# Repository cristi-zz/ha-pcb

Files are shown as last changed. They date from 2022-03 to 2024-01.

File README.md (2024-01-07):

## Home automation PCB

The story behind this, can be found [on my blog](https://visoft.ro/hello/expanding-the-stack-designing-a-pcb/2023/01/11/)

It will hold a series of breakout boards for I2C IO expanders, 1Wire drivers, ADCs. All are controlled with a Raspberry Pi 3B+.

The 220V actuators are controlled by a board with 16 mechanical relays. The board is in turn controlled by PCF8575 chip that takes I2C commands and controls 16 I/O pins. Board is active on low (optocouplers), PCF8575 can sink more current (than it could source). Perfect match.

The 16 relay board is separate, from this PCB, only a pin header connection is made.

The temperature sensors are DS18B20 that work on 1 wire protocol. These are already mounted with Ethernet cables terminated with RJ45. The sensors are read/driven by 4 ds2482s-100 chips (RJ45 terminals and ds2482s-100 are on this PCB).
The RJ jacks must be galvanic!

There are some other relays/contactors/voltages that needs monitoring, all done by 2 ADS1115 16-Bit ADC, present on board.

The chips are already sourced and live on their breakout boards. The PCB is mainly THT because of sourcing issues (eg can't find ds2482s-100 anywhere, will reuse existing breakouts). Only SMD are the 3.5 audio jacks (for ADC) again because no THT could be sourced atm.

The Raspberry Pi connector is only 20 pin wide because only the first few are used (5V, 3.3, SDA, SCL, GND)

There is a spurious bug, all relays are ON when the 16 relay board is powered but the Raspberry (that powers the rest of the circuits) is OFF. So, a solid state relay is used to cut power to the relay board when the RaPi is shutted down.

With the exception of ADCs, the schema and design choices follow the existing (4 years old) system.

This repo is mainly for reviewing purposes.

**The story behind this PCB is on [www.visoft.ro](https://www.visoft.ro/beginner/expanding-the-stack-designing-a-pcb/2372/)**

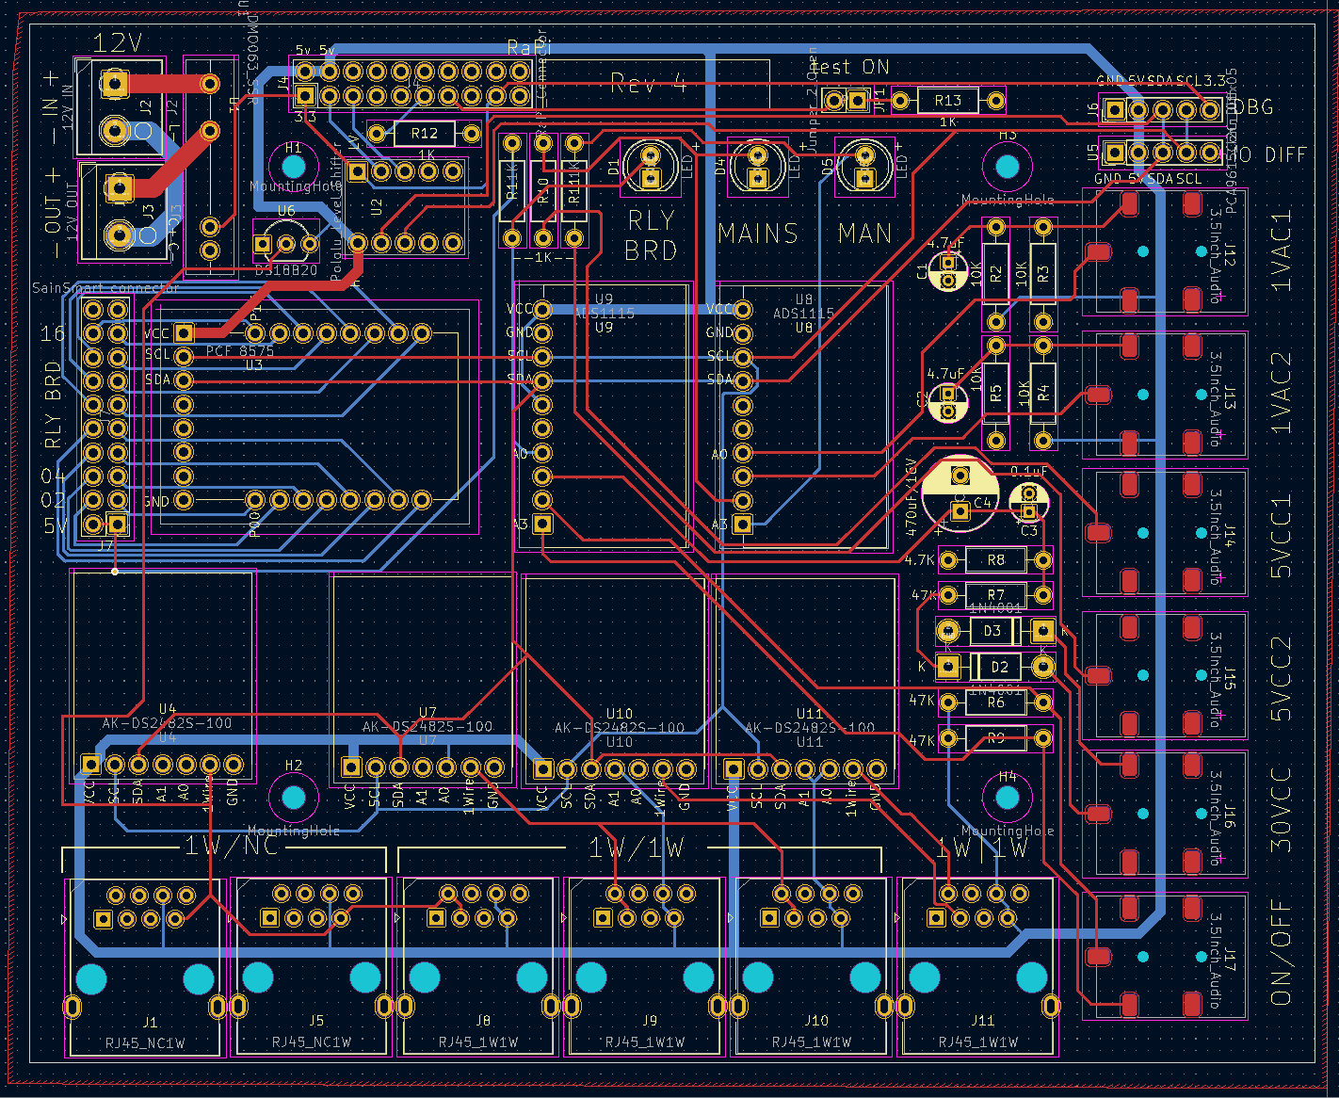
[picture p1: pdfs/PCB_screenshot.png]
PCB image with copper layers


A list with the devices

### Relay board that will be driven:
https://www.sainsmart.com/products/16-channel-12v-relay-module

### 16 channel IO expander that will drive the board:
https://www.artekit.eu/products/breakout-boards/io/ak-pcf8575-i2c-16-bit-io-expander-breakout/

### I2C level shifter (3.3 to 5V)
https://www.pololu.com/product/2595

### I2C to differential signals:
https://www.sparkfun.com/products/retired/14589

### 1Wire drivers:
https://www.artekit.eu/products/breakout-boards/io/ak-ds2482s-100/

### ADC:
https://www.adafruit.com/product/1085

Some ADC "watch" only for presence/absence of 5V power but some are listenting to CT sensors.
Quasi similar model: https://www.seeedstudio.com/Non-invasive-AC-Current-Sensor-30A-ma-p-519.html

### Solid state relay:
https://www.tme.eu/en/details/dmo063/dc-solid-state-relays/crydom/

Add comments here (as git issues) or on EEVBlog.

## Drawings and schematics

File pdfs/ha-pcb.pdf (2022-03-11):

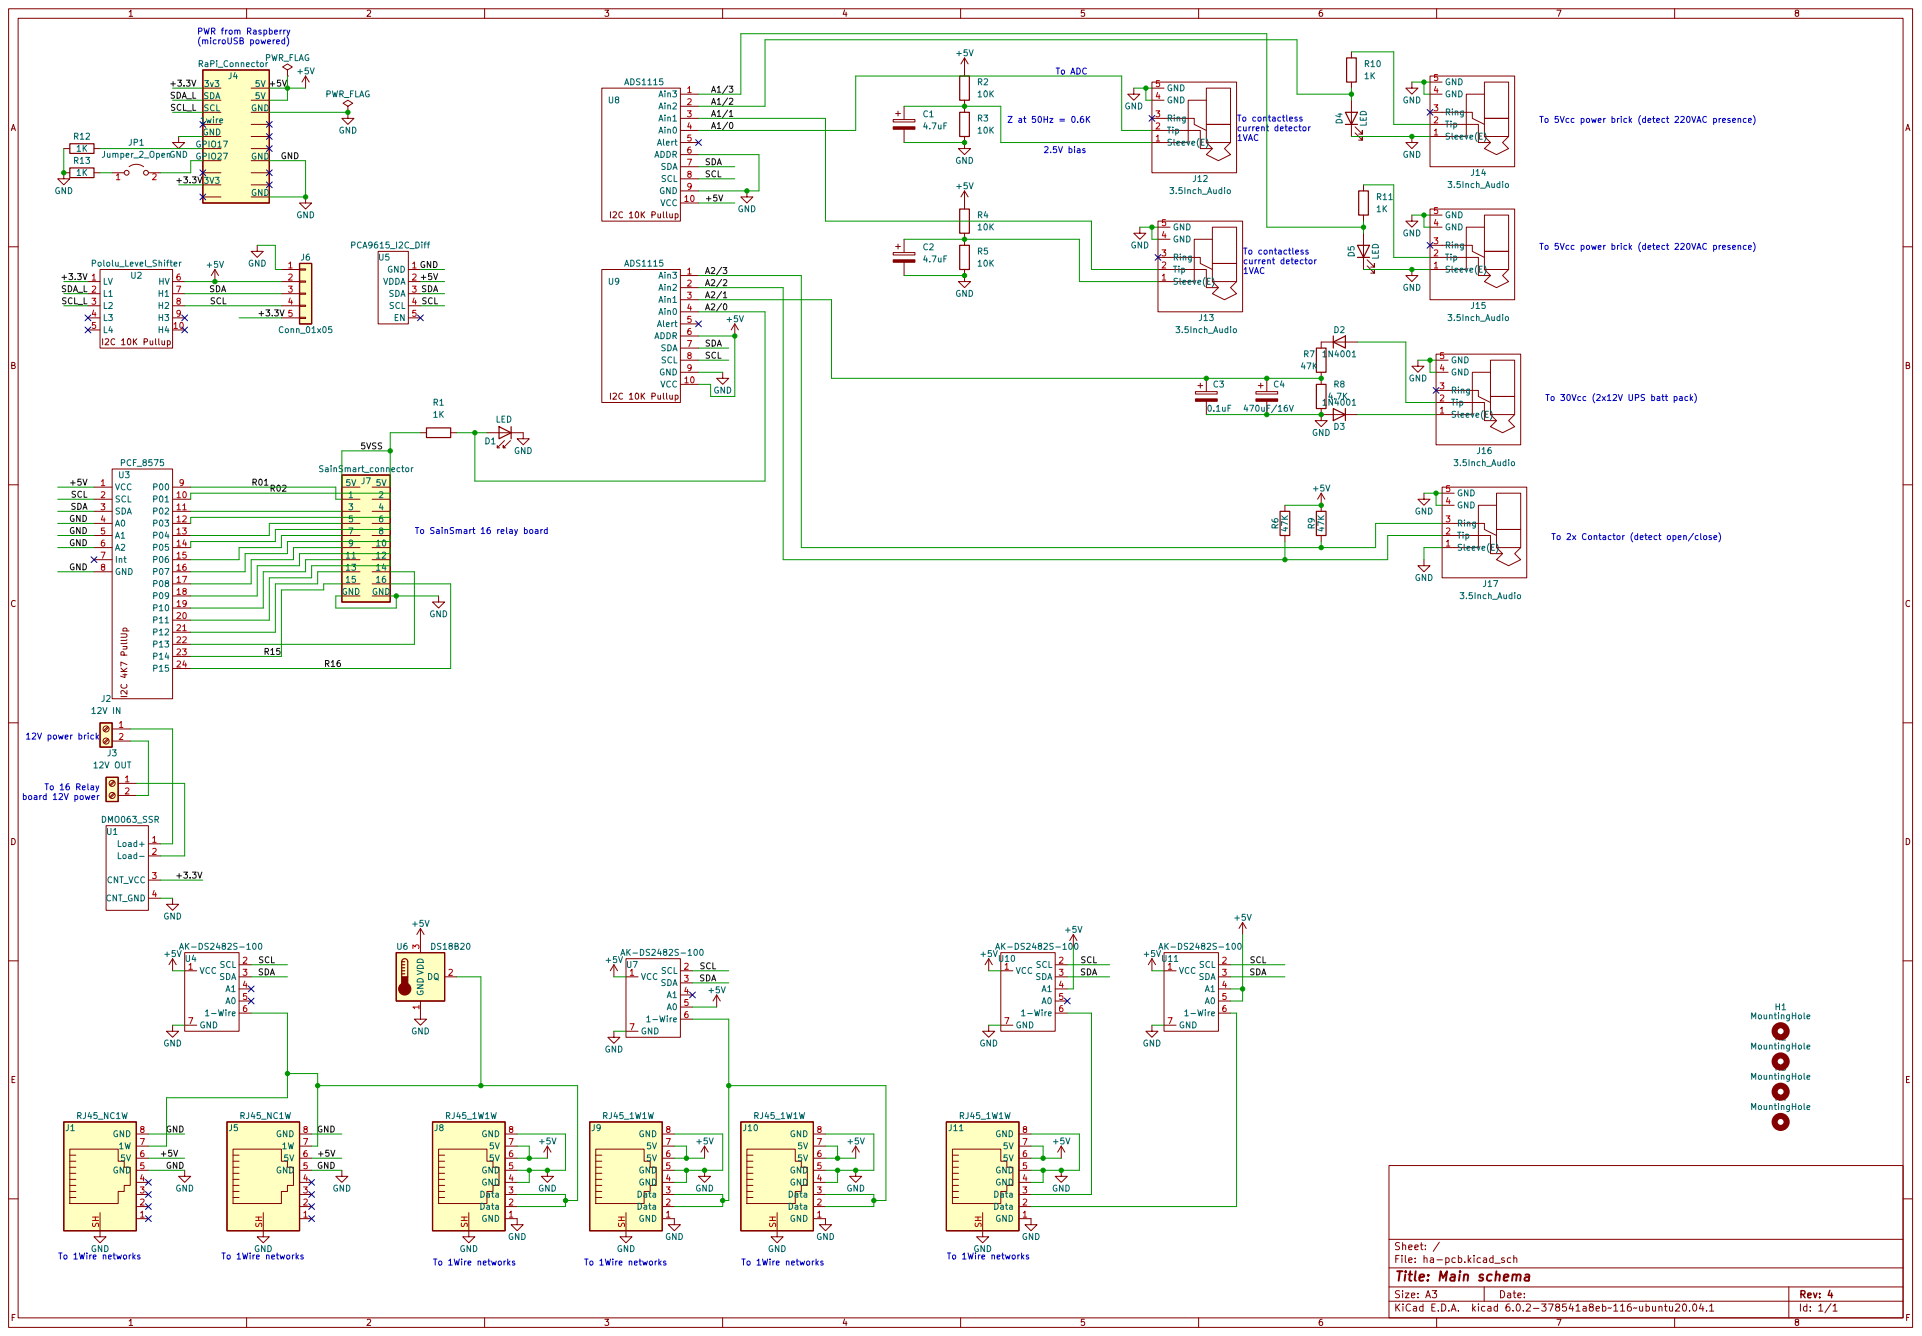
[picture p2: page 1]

To 5Vcc power brick (detect 220VAC presence)

To 30Vcc (2x12V UPS batt pack) To contactless
current detector 1VAC

5VSS R16 5V GND 5 6 7 8

Sleeve(E) 1 Tip 2 Ring 3 GND 4 GND 5

To SainSmart 16 relay board

File: ha-pcb.kicad_sch Sheet: / +5V

Id: 1/1 Title: Main schema

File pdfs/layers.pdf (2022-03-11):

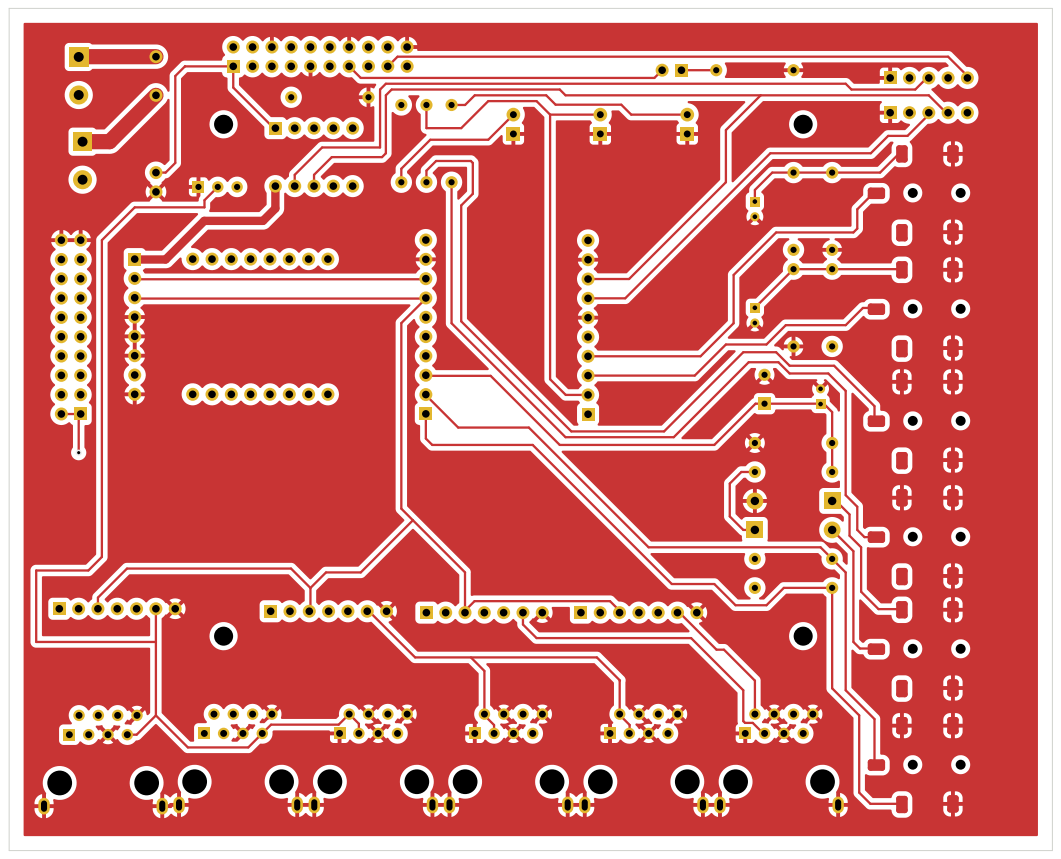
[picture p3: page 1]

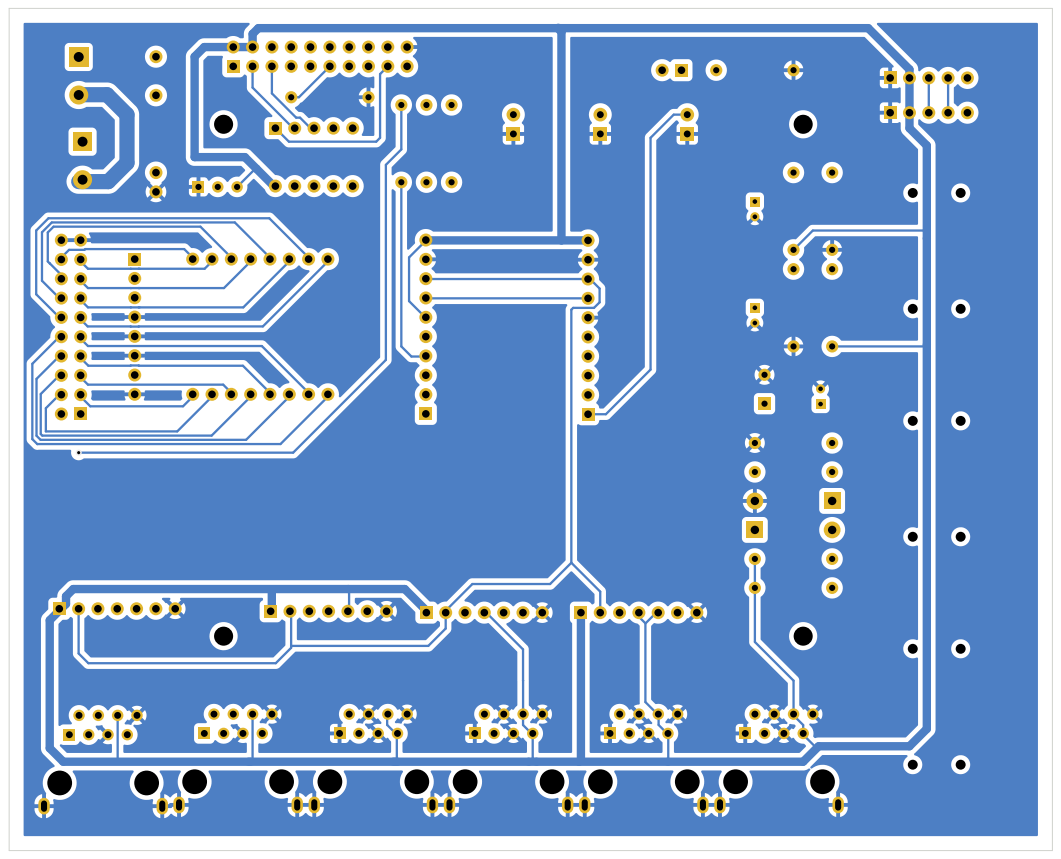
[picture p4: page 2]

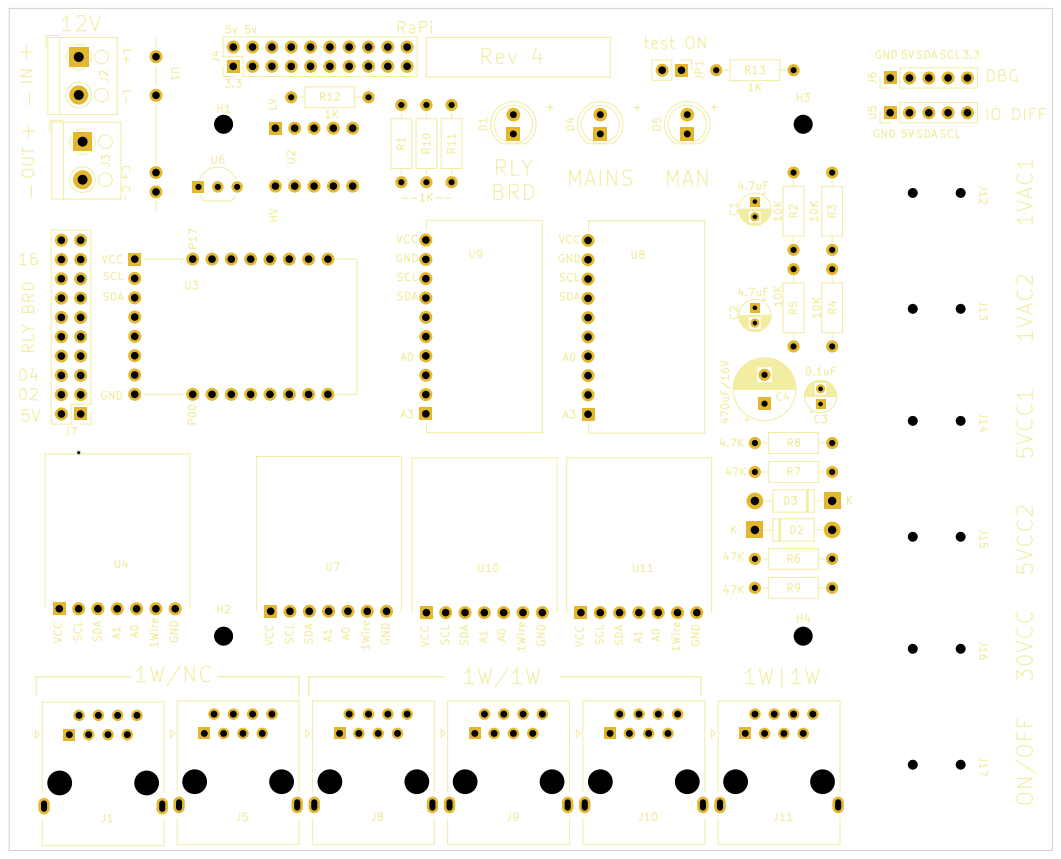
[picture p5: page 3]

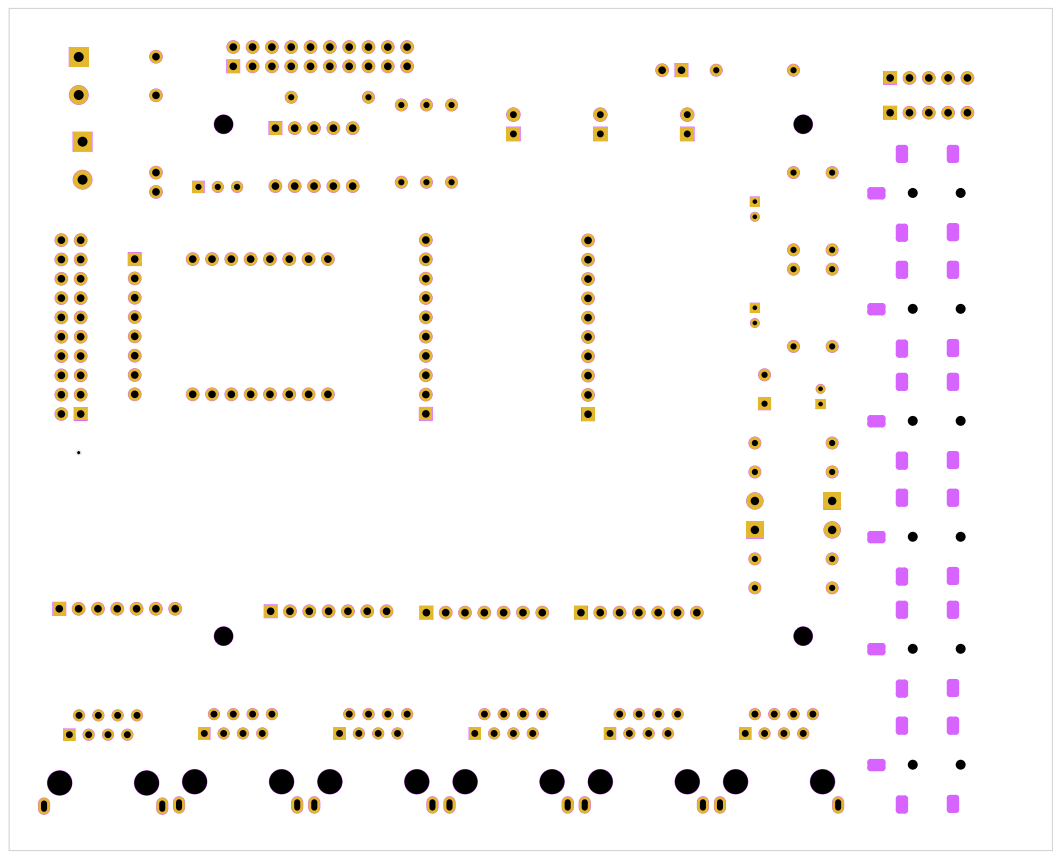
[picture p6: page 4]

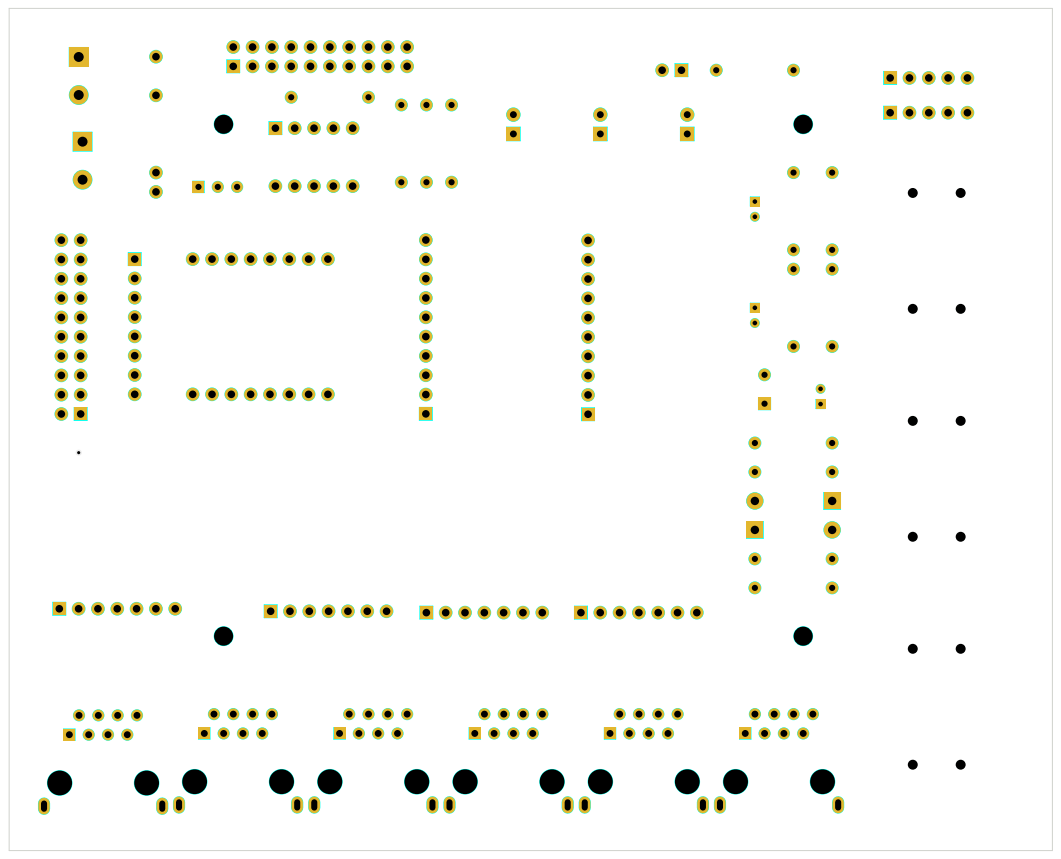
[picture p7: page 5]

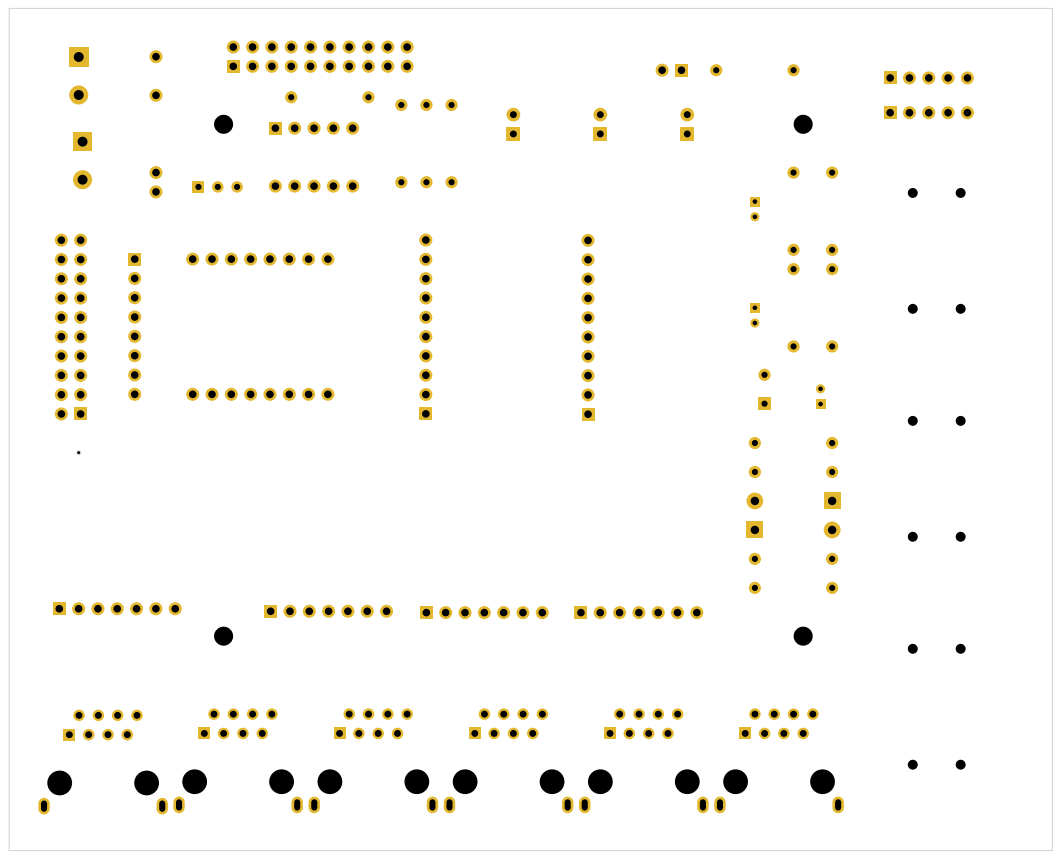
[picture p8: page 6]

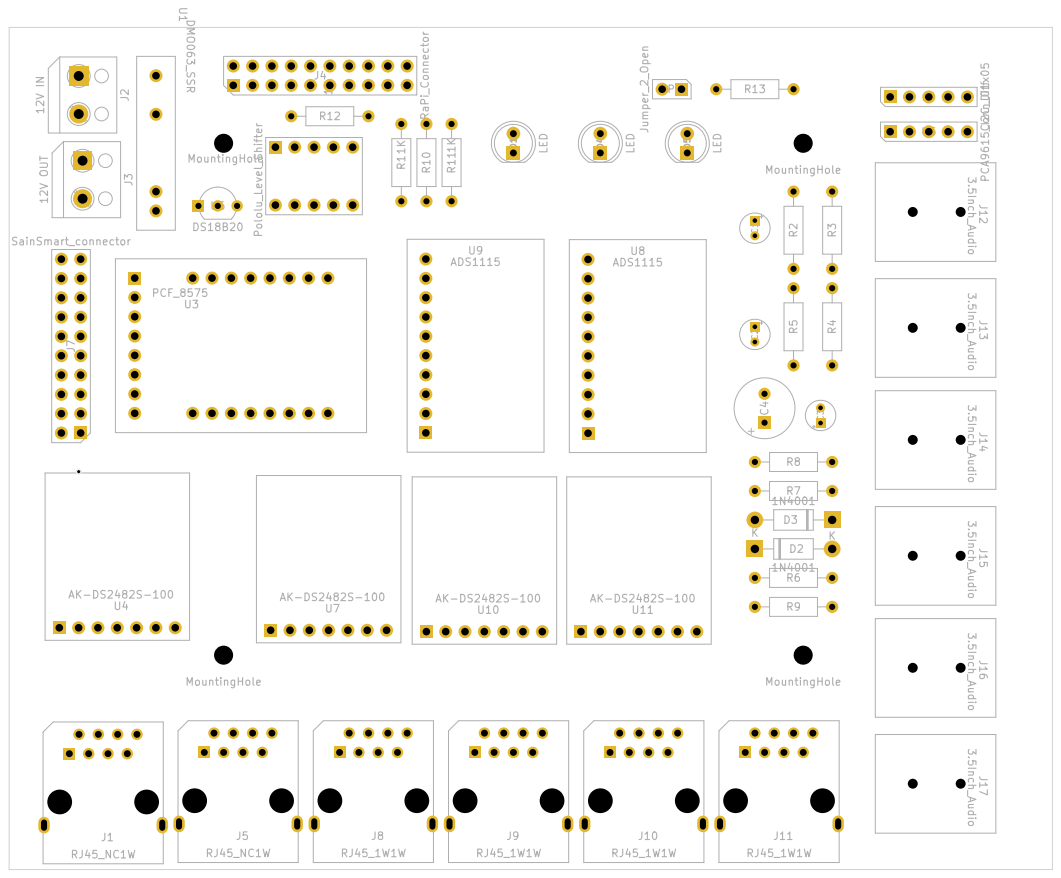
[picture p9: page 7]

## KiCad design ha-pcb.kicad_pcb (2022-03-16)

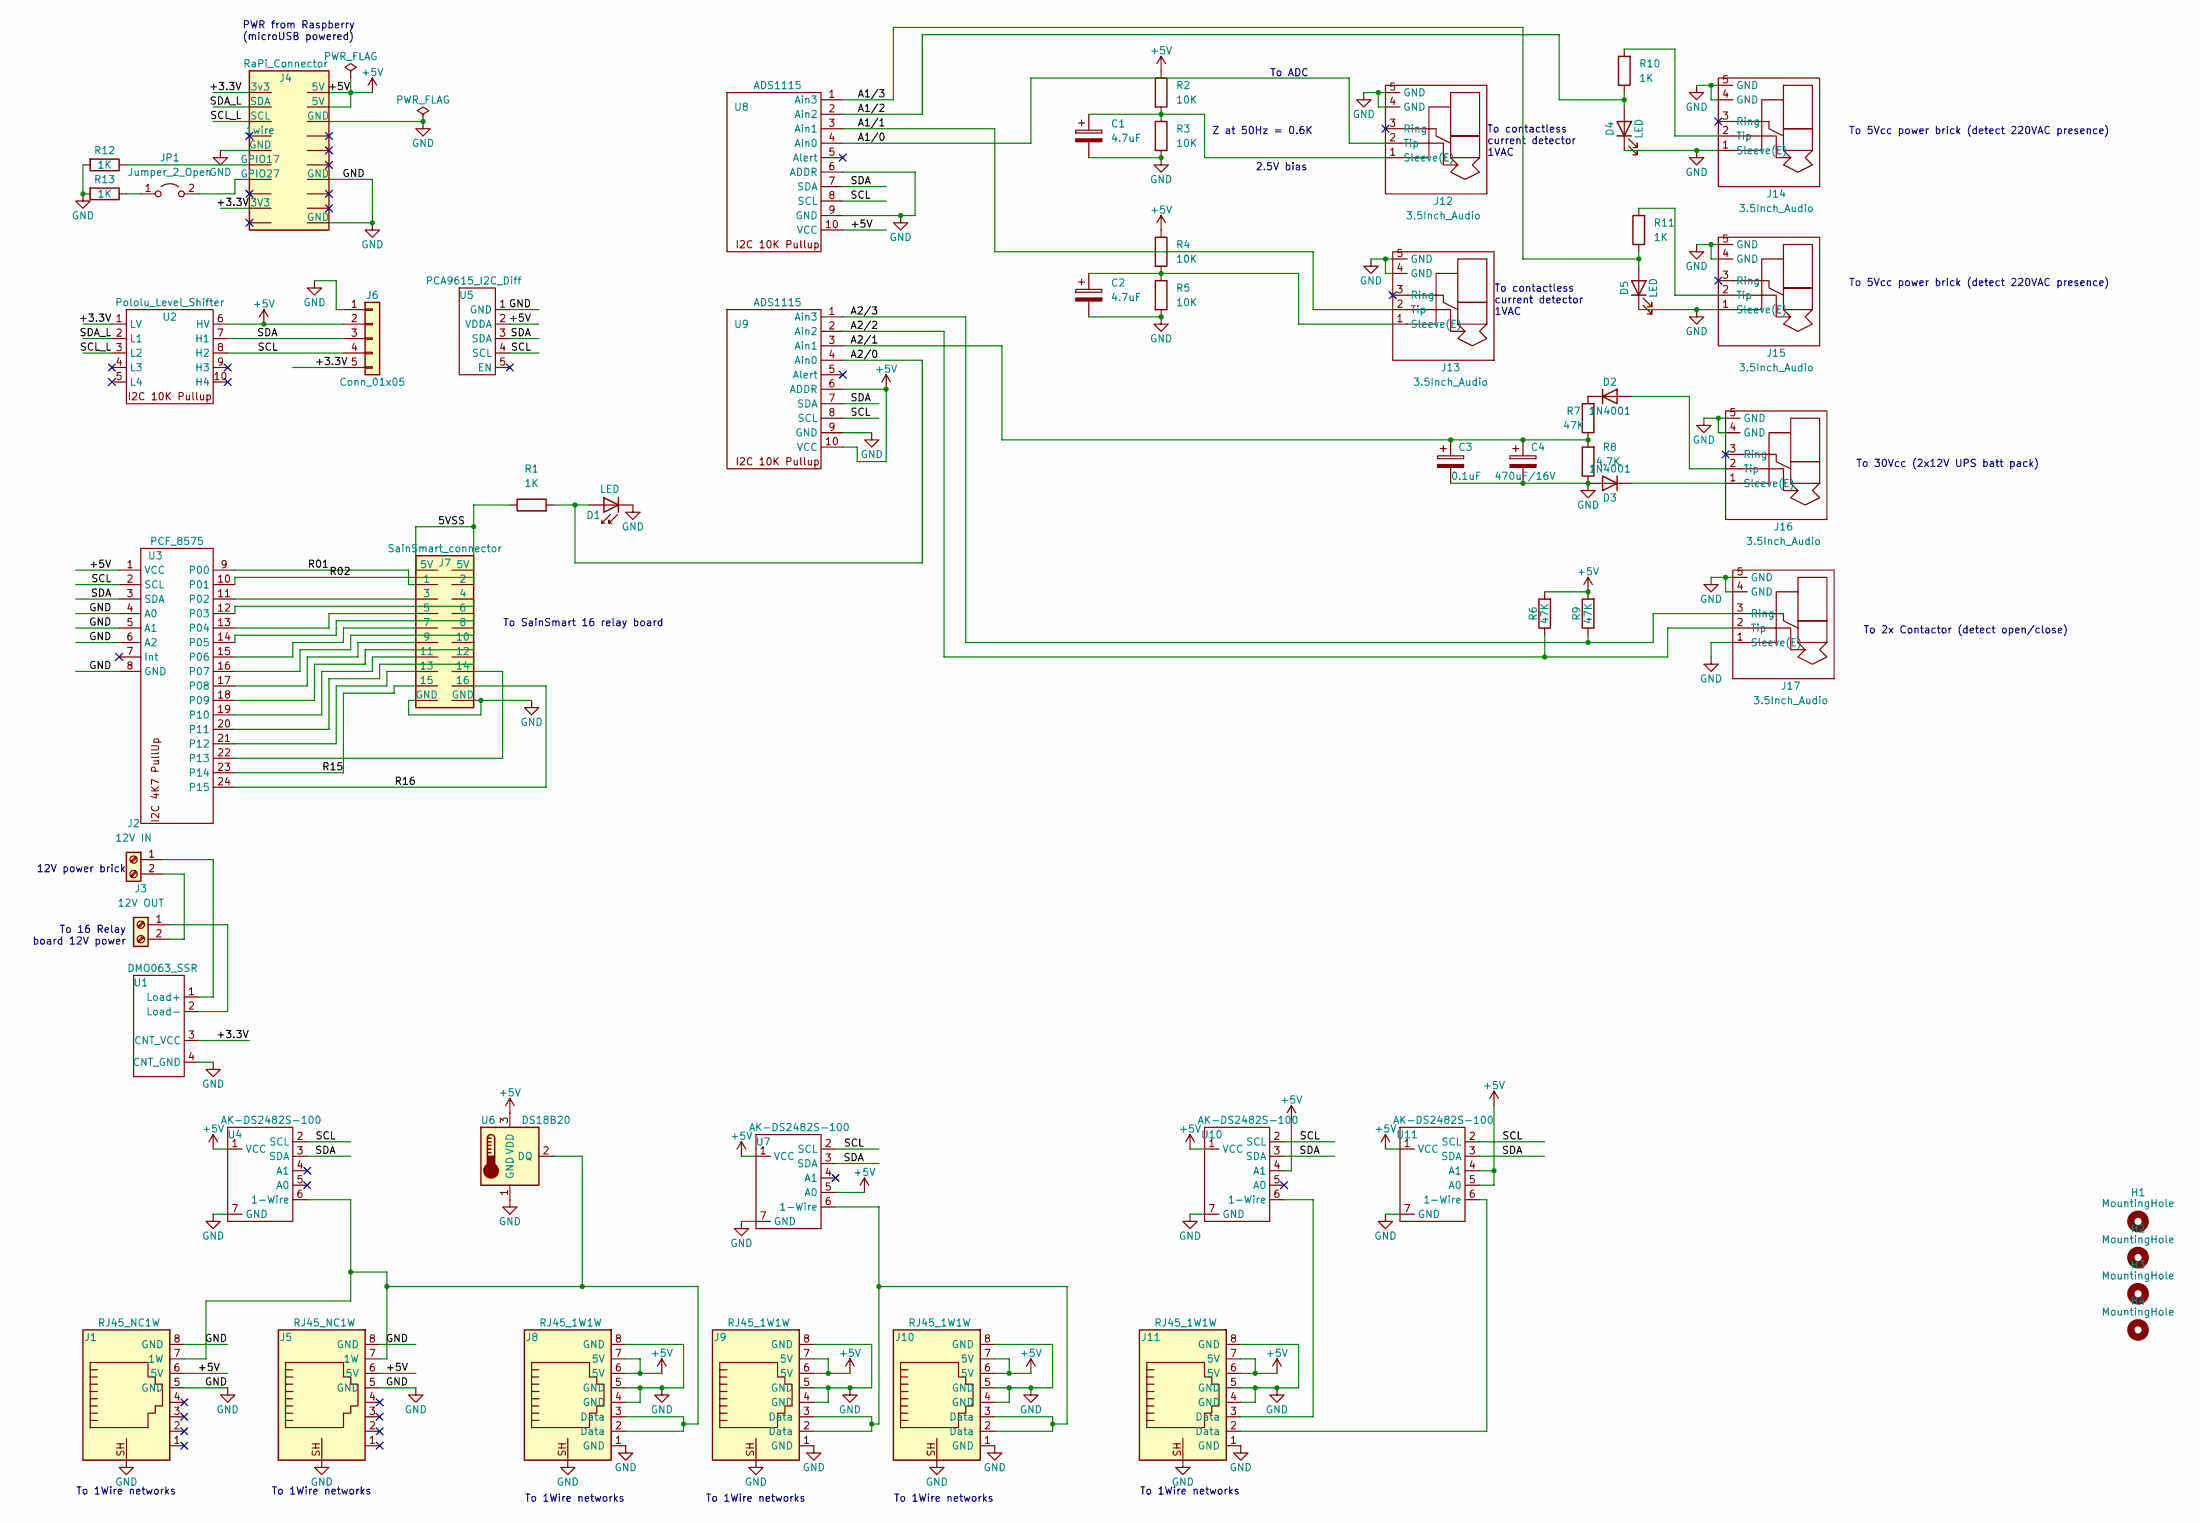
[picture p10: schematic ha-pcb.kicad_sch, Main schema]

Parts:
C1, C2: 4.7uF; CP_Radial_D4.0mm_P2.00mm
C3: 0.1uF; CP_Radial_D4.0mm_P2.00mm
C4: 470uF/16V; CP_Radial_D8.0mm_P3.80mm
D1, D4, D5: LED; LED_D5.0mm
D2, D3: 1N4001; D_DO-41_SOD81_P10.16mm_Horizontal
H1, H2, H3, H4: MountingHole; MountingHole_2.5mm
J1, J5: RJ45_NC1W; RJ45_Ninigi_GE_silver
J2: 12V IN; TerminalBlock_RND_205-00001_1x02_P5.00mm_Horizontal
J3: 12V OUT; TerminalBlock_RND_205-00001_1x02_P5.00mm_Horizontal
J4: RaPi_Connector; PinHeader_2x10_P2.54mm_Vertical
J6: Conn_01x05; PinHeader_1x05_P2.54mm_Vertical
J7: SainSmart_connector; PinHeader_2x10_P2.54mm_Vertical
J8, J9, J10, J11: RJ45_1W1W; RJ45_Ninigi_GE_silver
J12, J13, J14, J15, J16, J17: 3.5Inch_Audio; 3.5mmJack SMD
JP1: Jumper_2_Open; PinHeader_1x02_P2.54mm_Vertical
R1, R10, R11, R12, R13: 1K; R_Axial_DIN0207_L6.3mm_D2.5mm_P10.16mm_Horizontal
R2, R3, R4, R5: 10K; R_Axial_DIN0207_L6.3mm_D2.5mm_P10.16mm_Horizontal
R6, R7, R9: 47K; R_Axial_DIN0207_L6.3mm_D2.5mm_P10.16mm_Horizontal
R8: 4.7K; R_Axial_DIN0207_L6.3mm_D2.5mm_P10.16mm_Horizontal
U1: DMO063_SSR
U2: Pololu_Level_Shifter; Pololu Level Shifter
U3: PCF_8575
U4, U7, U10, U11: AK-DS2482S-100
U5: PCA9615_I2C_Diff; PinHeader_1x05_P2.54mm_Vertical
U6: DS18B20; TO-92_Inline_Wide
U8, U9: ADS1115

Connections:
+5V: J1.6 (5V), J4.2 (5V), J4.4 (5V), J5.6 (5V), J6.2, J8.6 (5V), J8.7 (5V), J9.6 (5V), J9.7 (5V), J10.6 (5V), J10.7 (5V), J11.6 (5V), J11.7 (5V), R2.1, R4.1, R6.2, R9.2, U2.6 (HV), U3.1 (VCC), U4.1 (VCC), U5.2 (VDDA), U6.3 (VDD), U7.1 (VCC), U7.5 (A0), U8.10 (VCC), U9.6 (ADDR), U9.10 (VCC), U10.1 (VCC), U10.4 (A1), U11.1 (VCC), U11.4 (A1), U11.5 (A0)
/5VSS: J7.1 (5V), J7.2 (5V), R1.1
/+3.3V: J4.1 (3v3), J4.17 (3V3), J6.5, U1.3 (CNT_VCC), U2.1 (LV)
/A1/0: J12.2 (Tip), U8.4 (Ain0)
/A1/1: J13.2 (Tip), U8.3 (Ain1)
/A1/2: D4.2 (A), R10.1, U8.2 (Ain2)
/A1/3: D5.2 (A), R11.1, U8.1 (Ain3)
/A2/0: D1.2 (A), R1.2, U9.4 (Ain0)
/A2/1: C3.1, C4.1, R7.1, R8.2, U9.3 (Ain1)
/A2/2: J17.2 (Tip), R6.1, U9.2 (Ain2)
/A2/3: J17.3 (Ring), R9.1, U9.1 (Ain3)
/R01: J7.3 (1), U3.9 (P00)
/R02: J7.4 (2), U3.10 (P01)
/R15: J7.17 (15), U3.23 (P14)
/R16: J7.18 (16), U3.24 (P15)
/SCL: J6.4, U2.8 (H2), U3.2 (SCL), U4.2 (SCL), U5.4 (SCL), U7.2 (SCL), U8.8 (SCL), U9.8 (SCL), U10.2 (SCL), U11.2 (SCL)
/SCL_L: J4.5 (SCL), U2.3 (L2)
/SDA: J6.3, U2.7 (H1), U3.3 (SDA), U4.3 (SDA), U5.3 (SDA), U7.3 (SDA), U8.7 (SDA), U9.7 (SDA), U10.3 (SDA), U11.3 (SDA)
/SDA_L: J4.3 (SDA), U2.2 (L1)
GND: C1.2, C2.2, C3.2, C4.2, D1.1 (K), D3.2 (A), D4.1 (K), D5.1 (K), J1.5 (GND), J1.8 (GND), J1.SH, J4.6 (GND), J4.9 (GND), J4.14 (GND), J4.20 (GND), J5.5 (GND), J5.8 (GND), J5.SH, J6.1, J7.19 (GND), J7.20 (GND), J8.1 (GND), J8.4 (GND), J8.5 (GND), J8.8 (GND), J8.SH, J9.1 (GND), J9.4 (GND), J9.5 (GND), J9.8 (GND), J9.SH, J10.1 (GND), J10.4 (GND), J10.5 (GND), J10.8 (GND), J10.SH, J11.1 (GND), J11.4 (GND), J11.5 (GND), J11.8 (GND), J11.SH, J12.4 (GND), J12.5 (GND), J13.4 (GND), J13.5 (GND), J14.1 (Sleeve(E)), J14.4 (GND), J14.5 (GND), J15.1 (Sleeve(E)), J15.4 (GND), J15.5 (GND), J16.4 (GND), J16.5 (GND), J17.1 (Sleeve(E)), J17.4 (GND), J17.5 (GND), R3.2, R5.2, R8.1, R12.2, R13.2, U1.4 (CNT_GND), U3.4 (A0), U3.5 (A1), U3.6 (A2), U3.8 (GND), U4.7 (GND), U5.1 (GND), U6.1 (GND), U7.7 (GND), U8.6 (ADDR), U8.9 (GND), U9.9 (GND), U10.7 (GND), U11.7 (GND)
unnamed: C1.1, J12.1 (Sleeve(E)), R2.2, R3.1
unnamed: C2.1, J13.1 (Sleeve(E)), R4.2, R5.1
unnamed: D2.1 (K), R7.2
unnamed: D2.2 (A), J16.2 (Tip)
unnamed: D3.1 (K), J16.1 (Sleeve(E))
unnamed: J1.7 (1W), J5.7 (1W), J8.2 (Data), J8.3 (Data), U4.6 (1-Wire), U6.2 (DQ)
unnamed: J2.1, U1.1 (Load+)
unnamed: J2.2, J3.2
unnamed: J3.1, U1.2 (Load-)
unnamed: J4.11 (GPIO17), R12.1
unnamed: J4.13 (GPIO27), JP1.2 (B)
unnamed: J7.5 (3), U3.11 (P02)
unnamed: J7.6 (4), U3.12 (P03)
unnamed: J7.7 (5), U3.13 (P04)
unnamed: J7.8 (6), U3.14 (P05)
unnamed: J7.9 (7), U3.15 (P06)
unnamed: J7.10 (8), U3.16 (P07)
unnamed: J7.11 (9), U3.17 (P08)
unnamed: J7.12 (10), U3.18 (P09)
unnamed: J7.13 (11), U3.19 (P10)
unnamed: J7.14 (12), U3.20 (P11)
unnamed: J7.15 (13), U3.21 (P12)
unnamed: J7.16 (14), U3.22 (P13)
unnamed: J9.2 (Data), J9.3 (Data), J10.2 (Data), J10.3 (Data), U7.6 (1-Wire)
unnamed: J11.2 (Data), U11.6 (1-Wire)
unnamed: J11.3 (Data), U10.6 (1-Wire)
unnamed: J14.2 (Tip), R10.2
unnamed: J15.2 (Tip), R11.2
unnamed: JP1.1 (A), R13.1

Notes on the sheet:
To ADC
Z at 50Hz = 0.6K
To 5Vcc power brick (detect 220VAC presence)
PWR from Raspberry (microUSB powered)
To 1Wire networks
To 30Vcc (2x12V UPS batt pack)
To contactless current detector 1VAC
2.5V bias
12V power brick
To 16 Relay board 12V power
To 2x Contactor (detect open/close)
To SainSmart 16 relay board

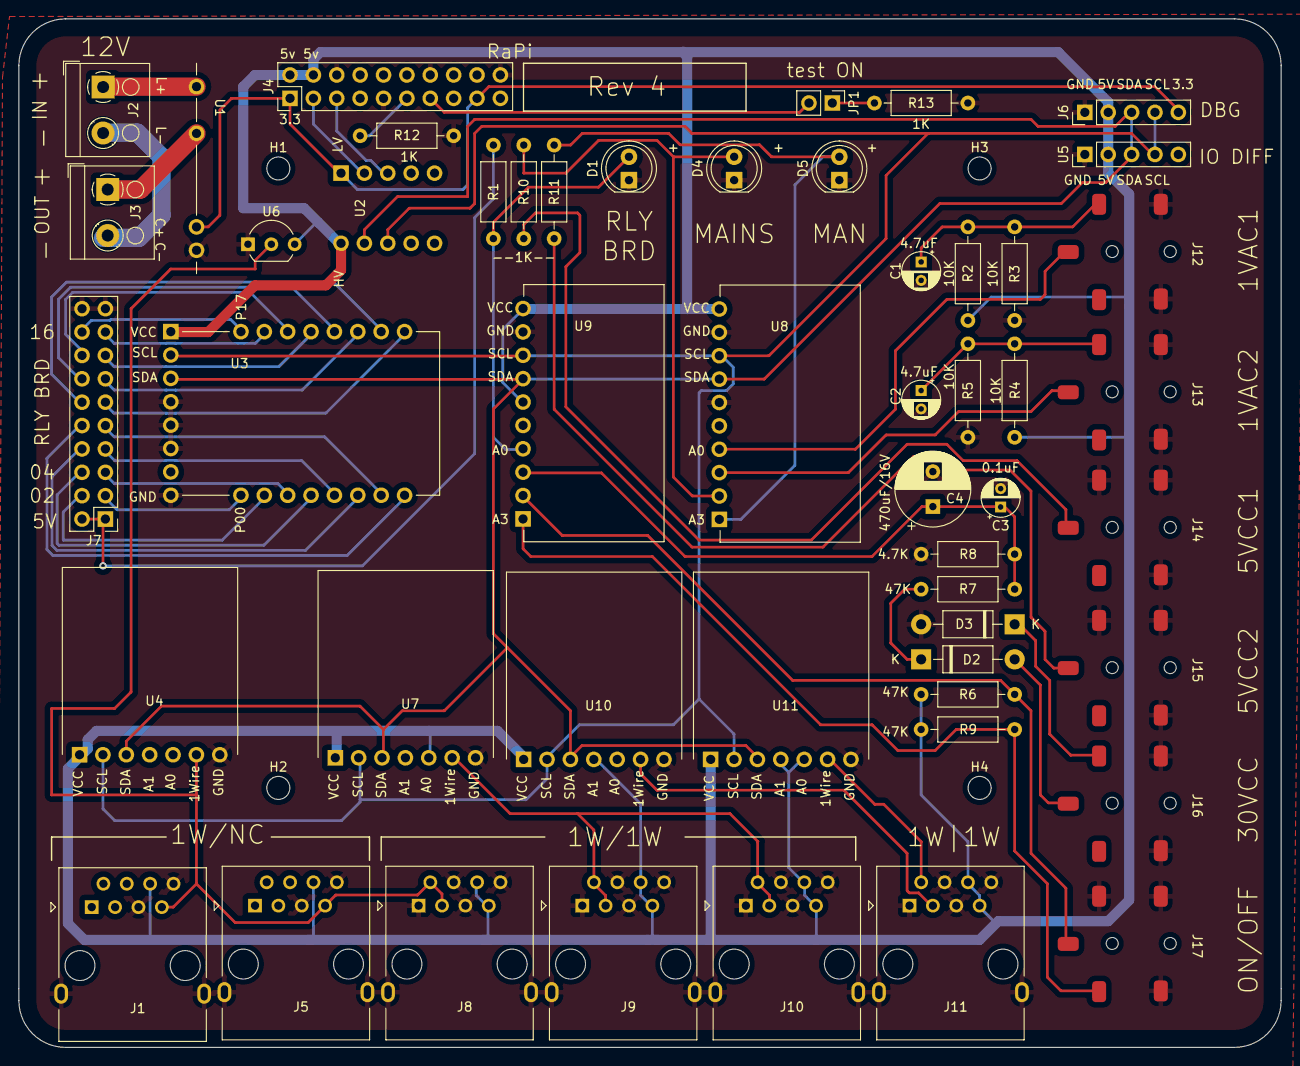
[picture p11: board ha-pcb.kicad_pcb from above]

Board: 2 copper layers, 137.2 x 111.8 mm, 55 parts (0 on the bottom side), 49 nets.

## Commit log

2022-03-09 Initial commit of ver3 board
    [ha-pcb-B_Cu.gbr, ha-pcb-B_Mask.gbr, ha-pcb-B_Silkscreen.gbr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]
2022-03-11 Incorporated feedback from forum.\nAdded two GPIOs for test marking
    [ha-pcb-B_Cu.gbr, ha-pcb-B_Mask.gbr, ha-pcb-B_Silkscreen.gbr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]
2022-03-11 regenerated gerbers
    [ha-pcb-B_Cu.gbr, ha-pcb-B_Mask.gbr, ha-pcb-B_Silkscreen.gbr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]
2022-03-16 Sent pcb to manufacturer step 1
    [ha-pcb-B_Cu.gbr, ha-pcb-B_Mask.gbr, ha-pcb-B_Silkscreen.gbr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]
2023-01-11 Insert image in readme.
